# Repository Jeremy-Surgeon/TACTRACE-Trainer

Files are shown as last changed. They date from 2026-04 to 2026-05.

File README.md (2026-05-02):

# TACTRACE Trainer

### 24V DC Wire Fault Injection Training System

> **Status:** V1.4 Prototype Complete — Validation Ongoing
> **Author:** Jeremy Surgeon
> **Built by an active-duty F-15 avionics technician for hands-on troubleshooting training.**

---

## Overview

TACTRACE is a portable, bench-top hardware trainer that teaches electrical troubleshooting through controlled fault injection on a 24 V DC bus. Trainees diagnose realistic wiring faults, opens, shorts to ground, and shorts to power, using a digital multimeter and standard test leads, replicating the diagnostic process used on the flight line.

Most current electrical-troubleshooting instruction is either purely theoretical or relies on large, expensive classroom systems. TACTRACE replaces that with a small, rugged, low-cost trainer that travels to the unit, the schoolhouse, or the bench, and gives junior maintainers a safe, repeatable environment for voltage tracing, continuity checking, and structured fault isolation.

---

## Why This Matters

Junior maintainers learn electrical troubleshooting from manuals, lectures, and the occasional broken component handed to them on the flight line. That mix produces uneven readiness; some maintainers can isolate a wiring fault with a multimeter in two minutes, others swap parts until the symptom disappears. The difference is hands-on repetition, and current training programs offer very little of it.

TACTRACE closes that gap. It puts a controlled, repeatable, multimeter-driven fault scenario in the hands of every junior maintainer who needs one — at the unit, in the schoolhouse, or on a workbench. The result is faster fault isolation, fewer parts swapped on a hunch, and measurable improvement in troubleshooting proficiency before the maintainer is put into the troubleshooting loop on a real aircraft system.

---

## Skills Demonstrated

- **Electrical design** — 24 V DC fault-injection circuit, contact-arc mitigation, deliberate component selection (breaker vs. fuse, 1P4T rotary, snubber sizing)
- **Schematic capture (KiCad)** — V1.0 through V1.4 revisions, with controlled annotation
- **Mechanical design (FreeCAD)** — Pelican 1120 enclosure model, panel-engraving art, test-point ergonomics
- **Iterative engineering discipline** — five hardware revisions with documented rationale at each step
- **Technical writing** — schematic, BOM, training guide, instructor reference, design briefs
- **Training curriculum design** — trainee worksheet, instructor evaluation rubric, scenario-based fault diagnosis
- **Troubleshooting methodology** — voltage tracing, continuity testing, evidence-based fault isolation

---

## Current Version — V1.4: Rotary Selector Contact Protection Revision

V1.4 is the current hardware revision. The contact-protection components are installed and operational; quantitative validation under measured load is in progress.

### Hardware Configuration

- 24 V DC supply via panel-mount barrel jack (external 24 V 3 A 72 W AC/DC adapter)
- 5 A pull-type circuit breaker, aircraft-style (Klixon 2TC2-5)
- Panel-mount toggle power switch
- 4-position **1P4T rotary selector switch** (fault selector)
- LED load with 1 kΩ 1 W series resistor
- Female panel-mount banana jacks for TP1 / TP2 / TP3 / TP4
- Pelican 1120 enclosure with engraved control panel
- **V1.4 contact-protection additions:**
  - **100 nF ceramic capacitor** connected from TP3 node to ground — for switching transient suppression during selector transitions
  - **100 Ω resistor** on the **Position 4 (Short to Power)** path — for current limiting through the rotary contact

> Validation of the V1.4 contact-protection components under measured load is pending — _Needs peer review._ The detailed V1.4 schematic with the 100 Ω on the Pos 4 path is published at [`hardware/schematics/v1_4_schematic_detailed.pdf`](hardware/schematics/v1_4_schematic_detailed.pdf); post-release housekeeping (refdes, peer-review confirmation of the 100 Ω routing, component-rating confirmation) is tracked in [`archive/SCHEMATIC_V1_4_REGENERATION.md`](archive/SCHEMATIC_V1_4_REGENERATION.md).

### Fault Selector Positions

| Position | Fault Condition | Description |
| ---: | --- | --- |
| 1 | Normal | Healthy circuit — power flows through the load to ground |
| 2 | Open Circuit | Path between TP2 and TP3 broken |
| 3 | Short to Ground | TP3 shorted to ground return |
| 4 | Short to Power  | TP3 fed from supply through 100 Ω current-limit on this path |

A 100 nF capacitor is permanently connected from the TP3 node to ground; it is not switched by the selector and is active in all positions, providing transient suppression during selector transitions.

### Test Points

| Label | Location | Function |
| ----- | --- | --- |
| TP1 | After circuit breaker, before switch | Verifies protected input power |
| TP2 | After power switch, before selector  | Verifies power entering the fault selector |
| TP3 | After fault selector, before load | Displays the selected fault condition |
| TP4 | Load return / ground reference | System ground reference |

---

## System Architecture

```
+24 V Supply  ->  CB (5 A pull)  ->  TP1
                                       |
                                       v
                                Power Switch
                                       |
                                       v
                                      TP2
                                       |
                                       v
                       Fault Selector (1P4T rotary)
                       |-- Pos 1: Normal pass-through
                       |-- Pos 2: Open
                       |-- Pos 3: Short to Ground
                       '-- Pos 4: Short to Power (100 ohm on path)
                                       |
                                       v
                                      TP3 ---||--- GND   (100 nF transient cap)
                                       |
                                       v
                            1 kohm  ->  LED  ->  TP4 / GND
```

The rotary selector determines the behavior of the TP3 node, allowing the trainee to deduce the active fault by comparing measurements at TP1–TP4.

---

## V1.4 Schematic

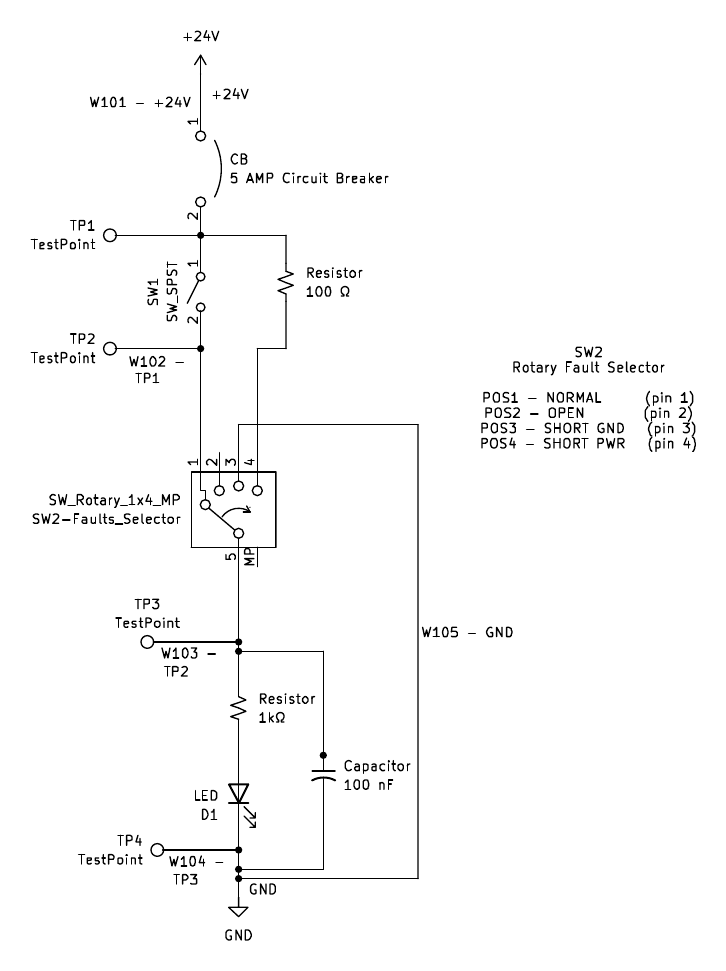
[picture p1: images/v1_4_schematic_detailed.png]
TACTRACE V1.4 Detailed Schematic


The V1.4 detailed schematic shows the full signal path from the +24 V supply through the circuit breaker (CB), main power switch (SW1), the 1P4T rotary fault selector (SW2), the 100 nF transient-suppression capacitor on the TP3 node, the 1 kΩ load resistor + LED, and back to GND. The 100 Ω current-limit feeding **Pos 4 (Short to Power)** is drawn explicitly, fed from the post-breaker rail. Reference designators (R1, C1, …) are not yet annotated and a peer-review confirmation of the 100 Ω routing intent is pending — see [`archive/SCHEMATIC_V1_4_REGENERATION.md`](archive/SCHEMATIC_V1_4_REGENERATION.md) for the post-release housekeeping list.

The PDF exports and KiCad source are in [`hardware/schematics/`](hardware/schematics/) and [`hardware/kicad/`](hardware/kicad/). A simplified block-level view is also available at [`hardware/schematics/v1_4_schematic_simplified.pdf`](hardware/schematics/v1_4_schematic_simplified.pdf) for orientation.

---

## V1.4 Panel Engraving

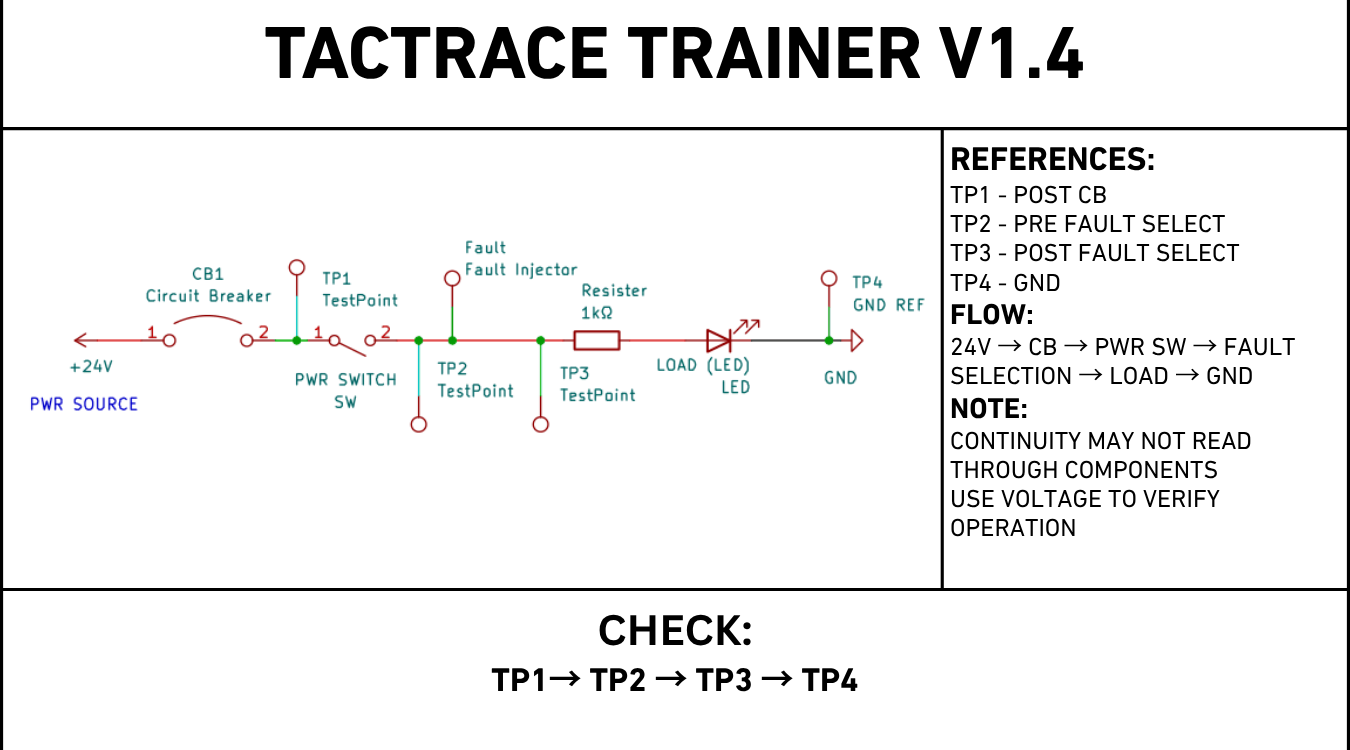
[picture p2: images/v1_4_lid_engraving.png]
TACTRACE V1.4 Lid Engraving Reference


The lid engraving doubles as a quick-reference card: test-point flow (TP1 → TP2 → TP3 → TP4), system flow (24 V → CB → PWR SW → FAULT SELECTION → LOAD → GND), and the reminder that continuity may not read through the load — voltage measurements should be used to confirm operation.

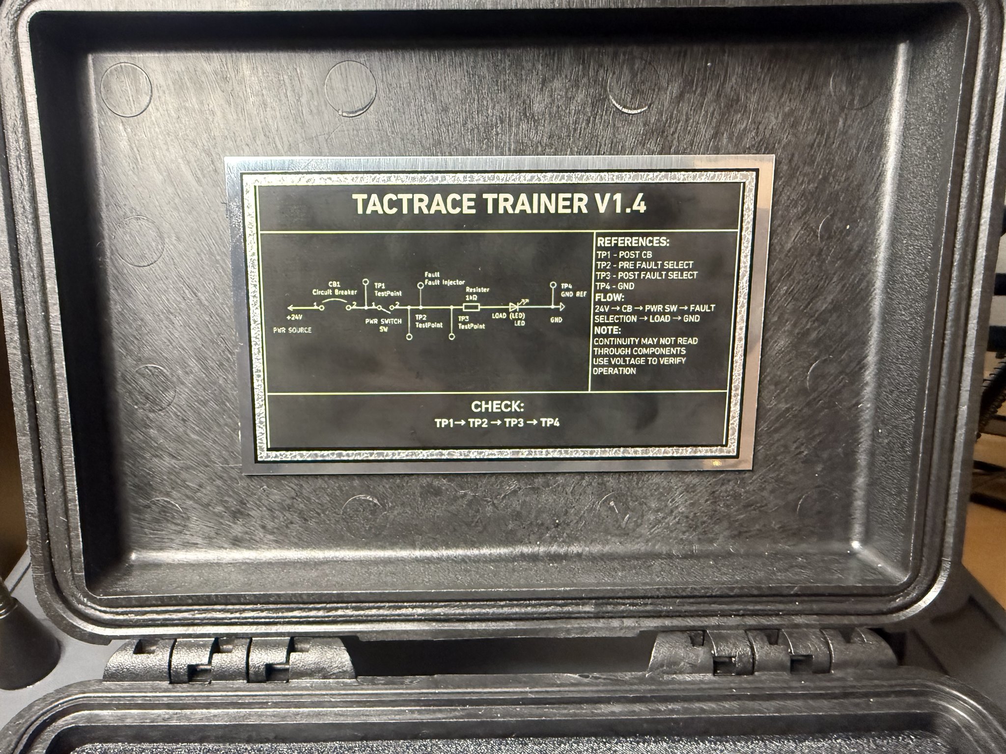
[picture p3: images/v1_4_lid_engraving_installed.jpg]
V1.4 Lid Engraving — Installed


The reference plate installed in the lid of the V1.4 enclosure — visible to the trainee while the unit is open and powered.

---

## Training Use Case

Instructors set the rotary to an unknown fault and ask the trainee to diagnose it. Trainees use TACTRACE to measure voltage at TP1–TP4 under each fault condition, recognize the electrical signature of opens, shorts to ground, and shorts to power, and practice systematic, evidence-based troubleshooting.

The full V1 training guide PDF (trainee worksheet + instructor reference + evaluation rubric) is in [`docs/TACTRACE_V1_Training_Guide.pdf`](docs/TACTRACE_V1_Training_Guide.pdf). The V1.4 quickstart — written for a maintainer who has never seen the device — is at [`docs/Quickstart.md`](docs/Quickstart.md). A V1.4-revised full training guide that maps the V1 three-test-point set to the V1.4 four-test-point set is in progress.

---

## Hardware & Documentation Deliverables

| Asset | Location | Status |
| --- | --- | --- |
| V1.4 detailed schematic (KiCad export, PDF) | [`hardware/schematics/v1_4_schematic_detailed.pdf`](hardware/schematics/v1_4_schematic_detailed.pdf) | Published |
| V1.4 simplified schematic (PDF) | [`hardware/schematics/v1_4_schematic_simplified.pdf`](hardware/schematics/v1_4_schematic_simplified.pdf) | Published |
| V1.4 KiCad source | [`hardware/kicad/`](hardware/kicad/) | Published |
| Bill of materials (CSV, machine-readable) | [`hardware/BOM.csv`](hardware/BOM.csv) | Published |
| Bill of materials (PDF, human-readable) | [`hardware/BOM.pdf`](hardware/BOM.pdf) | Published |
| V1.4 quickstart | [`docs/Quickstart.md`](docs/Quickstart.md) | Published |
| V1 training guide PDF (interim) | [`docs/TACTRACE_V1_Training_Guide.pdf`](docs/TACTRACE_V1_Training_Guide.pdf) | Interim — V1.4 revision in progress |
| User-feedback questionnaire (instrument) | [`docs/TACTRACE_User_Feedback_Questionnaire.csv`](docs/TACTRACE_User_Feedback_Questionnaire.csv) | Published |
| Peer-feedback summary (initial round, _n_ = 5) | [`docs/Peer_Feedback_Summary.md`](docs/Peer_Feedback_Summary.md) | Published |
| Demo video (~60 s) | Linked from the GitHub release page (file too large to commit to the repo body) | Release attachment |
| Enclosure CAD | [`hardware/enclosure/`](hardware/enclosure/) | **Deferred** — see Enclosure Status below |

---

## Validation & Initial Peer Feedback

Initial peer feedback was collected from **avionics maintainers** across three skill levels: two 3-Level Apprentices, two 5-Level Journeymen, and one 7-Level Craftsman (n = 5). All five reported the test points and controls were clear, and that the trainer helped them understand the troubleshooting concepts being taught. A summary of the responses and a transcript of the open-text themes is in [`docs/Peer_Feedback_Summary.md`](docs/Peer_Feedback_Summary.md); the underlying questionnaire is at [`docs/TACTRACE_User_Feedback_Questionnaire.csv`](docs/TACTRACE_User_Feedback_Questionnaire.csv) (surveyor identifying information masked).

This is **preliminary feedback at _n_ = 5** — it indicates that the trainer was usable and that the test-point layout communicated clearly to the reviewers. It does **not** constitute validation of training effectiveness, learning gains, retention, or transfer to flight-line tasks. A larger feedback round with pre/post measurement is a separate effort, not a V1.4 deliverable.

The V1.4 contact-protection components (100 nF capacitor, 100 Ω resistor) are installed and operational, but **quantitative validation under measured load is pending**. Where the schematic, BOM, or documentation states a value or placement that has not yet been confirmed by measured testing or independent peer review, that item is flagged in this README as **"Needs peer review"** or in the source files as **"Needs verification."**

---

## Enclosure Status

The TACTRACE V1.4 trainer is housed in a **Pelican 1120 enclosure** with an engraved control panel and engraved lid quick-reference plate (both V1.4 deliverables, photographed in this README). The mechanical layout is operational and trainee-validated by the initial peer-feedback round.

**A finalized 3-D enclosure CAD model is not part of the V1.4 release.** The CAD work is intentionally deferred while the project transitions from FreeCAD to **SolidWorks** (license pending). The current enclosure is documented through the panel-engraving art, the lid-engraving art, and the photographic record in [`images/`](images/) — not through a parametric CAD source. The `hardware/enclosure/` folder is reserved for the SolidWorks model and exported PDFs, and will be populated in a later revision.

This means the repo currently lets a maintainer **rebuild the V1.4 electrical system** from the schematic and BOM, but **does not** let them re-machine an identical enclosure from CAD without consulting the photographs and the panel-engraving art. The gap is intentional and documented; it is not an oversight.

---

## Key Engineering Decisions

- **5 A pull-type circuit breaker** instead of an automotive fuse — for realism, repeatability, and physical authority during instruction.
- **1P4T rotary selector switch** instead of a fan-style multi-pole — so each fault position electrically isolates the others.
- **Female panel-mount banana jacks** — for compatibility with standard maintainer test leads.
- **1 kΩ 1 W resistor** for thermal margin at 24 V (≈576 mW worst-case dissipation).
- **M2 mounting hardware** to reduce perfboard damage during enclosure work.
- **100 nF ceramic capacitor from TP3 to ground (V1.4)** — for switching transient suppression during selector transitions, suppressing the contact-arc transient that occurs as the rotary wiper makes/breaks under load. _Needs peer review under measured load._
- **100 Ω resistor on the Short-to-Power path (V1.4)** — for current limiting through the rotary contact during the Pos 4 transition. _Needs peer review under measured load._

---

## Known Limitations

- Mechanical rotary switching is the long-term scaling bottleneck — it limits fault count and introduces wear.
- Single-channel: only one fault can be active at a time.
- V1.4 arc-mitigation parts (100 nF / 100 Ω) reduce — but do not eliminate — switching transients on the rotary contacts. _Quantitative validation pending._
- TACTRACE is **not** certified for use on or with airworthy aircraft. Trainer use only.

---

## Version History

### V1.4 — Rotary Selector Contact Protection Revision

- Added 100 nF ceramic capacitor from TP3 to ground for switching transient suppression during selector transitions
- Added 100 Ω resistor on the Position 4 (Short to Power) path for current limiting through the rotary contact
- Refined V1.4 schematic and produced the lid-engraving panel quick-reference card

### V1.3 — Test Point Architecture Refinement

- Relocated TP1 to read protected input power (post-breaker, pre-switch)
- Separated protection, control, and fault-injection stages into distinct measurable nodes
- Improved diagnostic clarity for power distribution faults

### V1.2 — Aircraft-Realism Pass

- Replaced automotive fuse with aircraft-style 5 A pull-type circuit breaker
- Transitioned from male banana plugs to panel-mounted female banana jacks

### V1.1 — Enclosure Integration

- Integrated components into a Pelican 1120 enclosure with structured control panel layout
- Improved durability and portability for transport between training sites

### V1.0 — Functional Validation

- Initial circuit concept, four-position rotary fault selector, and bench-validated fault injection

The full per-version changelog is maintained in [`CHANGELOG.md`](CHANGELOG.md).

---

## Roadmap — Toward V2

V1.4 is the final mechanical-switching revision. V2 transitions to a solid-state, microcontroller-driven fault matrix.

- **MOSFET-based solid-state fault injection** replacing mechanical rotary switching
- **Microcontroller-controlled** scenario selection
- **16+ programmable faults**, including intermittent and time-based conditions
- Instructor-side scenario presets with **randomized fault delivery** for evaluation
- **Aircraft-style cannon plug connectors** to mirror real flight-line interfaces
- Improved enclosure layout, serviceability, and instrumentation
- Long-term: instructor-controlled training mode with student-evaluation logging, modular expansion across multiple wire systems, scalable deployable platform for squadrons, schoolhouses, and maintenance training units

A formal V2 design brief will be published in `docs/V2_design_brief.md`.

---

## Prototype Photos

The physical enclosure and front-panel layout are unchanged from V1.3; the V1.4 revisions are the engraved lid quick-reference and the internal contact-protection components on the rotary-selector paths.

### V1.4 Trainer — Lid Engraved, Front Panel Powered

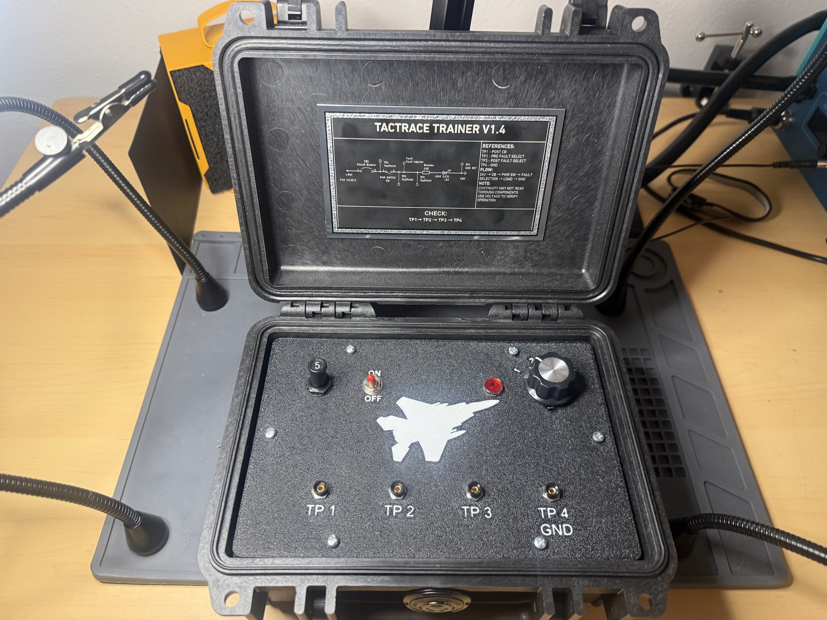
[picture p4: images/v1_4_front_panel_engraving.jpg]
TACTRACE V1.4 — engraved lid and powered front panel


### V1.4 Internal Wiring

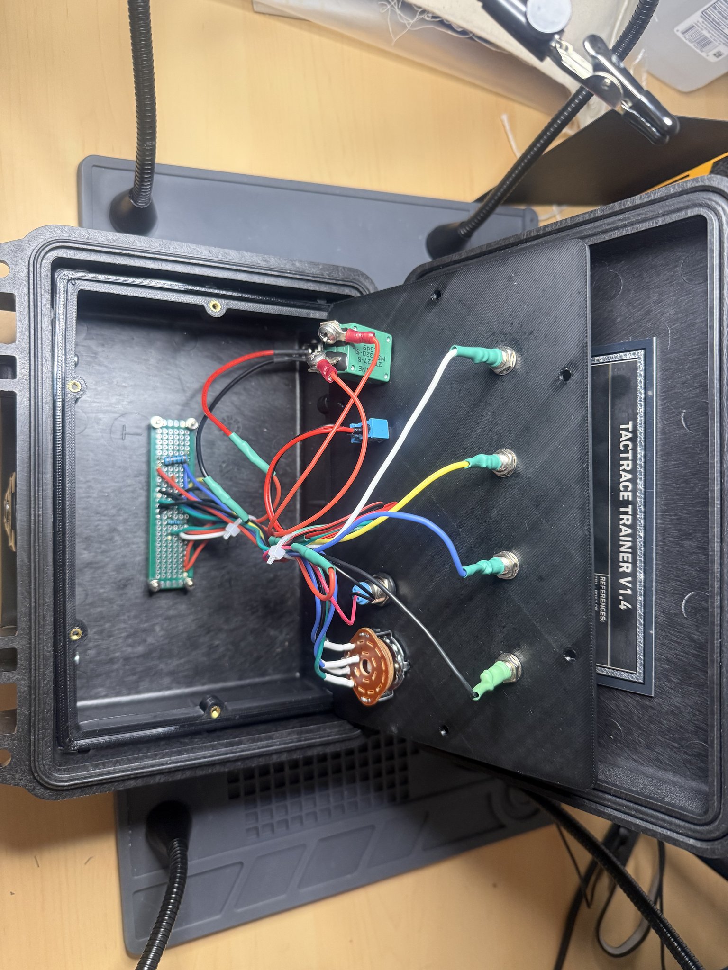
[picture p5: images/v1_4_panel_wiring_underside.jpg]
V1.4 Internal Wiring — Underside of Front Panel


### V1.4 Perfboard — Component Side

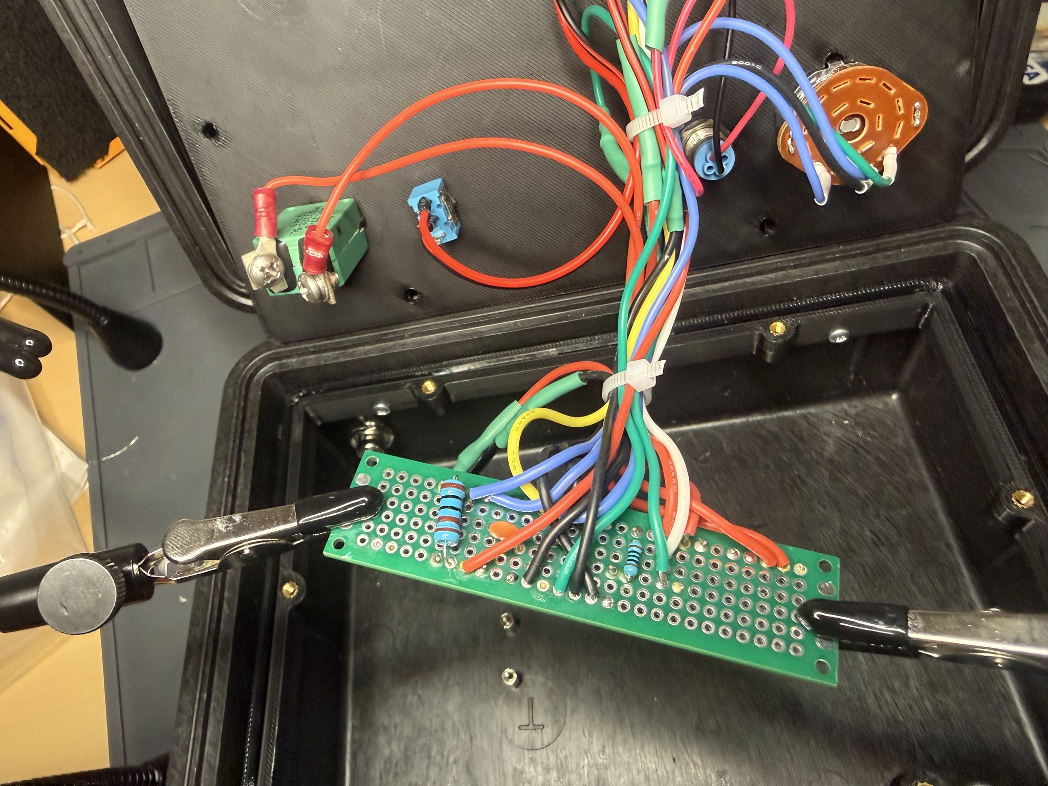
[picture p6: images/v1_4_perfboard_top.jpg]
V1.4 Perfboard — Top


### V1.4 Perfboard — Solder Side

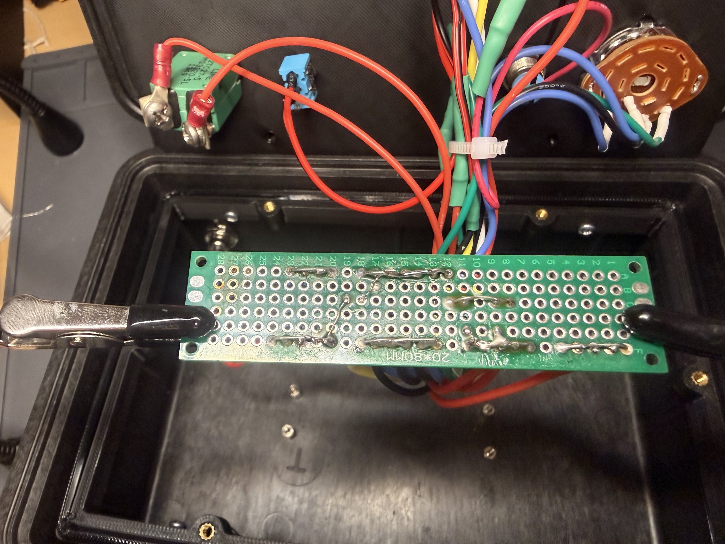
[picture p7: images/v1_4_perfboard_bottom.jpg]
V1.4 Perfboard — Bottom


### Earlier Revision Reference (V1.3)

The V1.3 prototype shots below are retained for revision-history context — the V1.4 trainer above is the current build.

<details>
<summary>V1.3 prototype photos</summary>

V1.3 Front Panel
V1.3 Front Panel — Powered
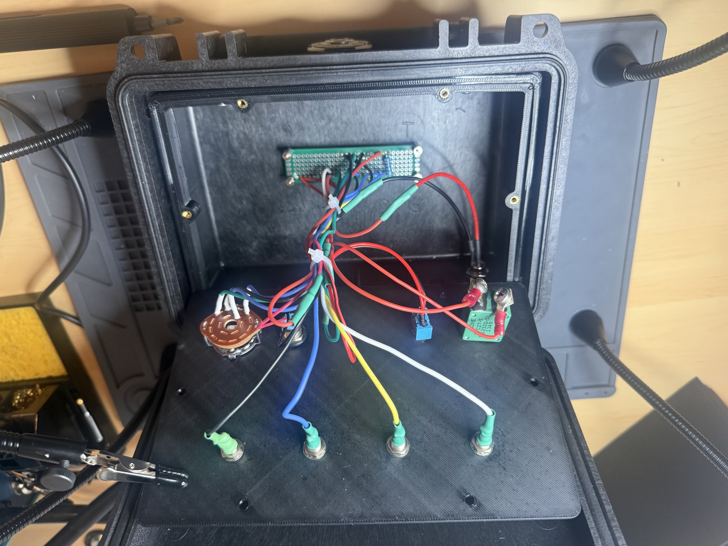
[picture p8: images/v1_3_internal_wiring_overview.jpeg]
V1.3 Internal Wiring

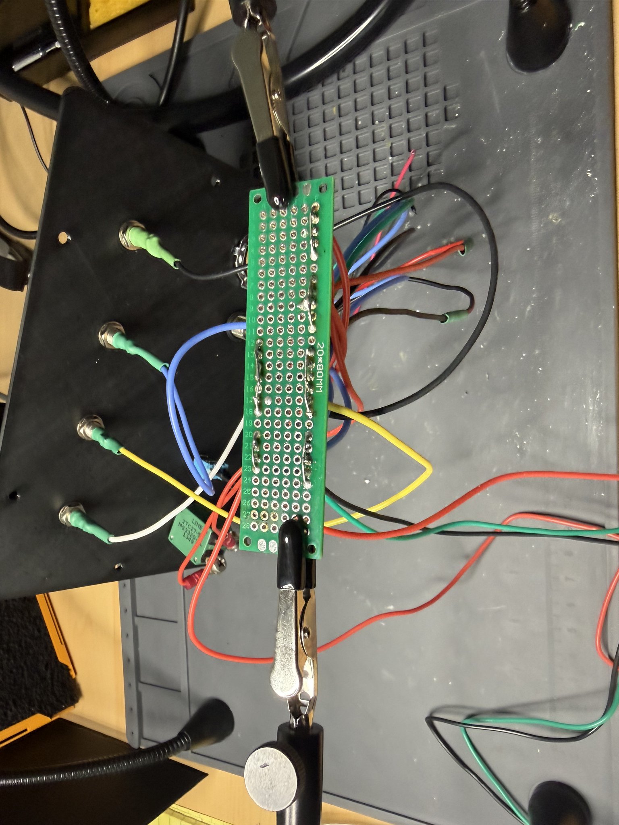
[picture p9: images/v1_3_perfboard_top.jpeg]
V1.3 Perfboard


</details>

---

## Lessons Learned

- Switching under load produces measurable contact arcing on a mechanical rotary — design has to plan for it, not ignore it.
- Switch and connector selection have an outsized effect on usability and safety; a 1P4T rotary selector behaves very differently from a fan-style multi-pole switch.
- Mechanical layout — test-point spacing, label placement, enclosure ergonomics — is as important to training value as the electrical design.
- Separating circuit protection, control, and fault injection into distinct measurable nodes (TP1 / TP2 / TP3) directly improves diagnostic clarity.
- Component selection (breaker vs. fuse, panel jacks vs. plugs, engraved labels) directly affects how the trainer feels in a maintainer's hands and how quickly trainees learn from it.

---

## Repository Layout

```
TACTRACE-Trainer/
├── README.md          ← project overview (this file)
├── CHANGELOG.md       ← per-version change history
├── LICENSE            ← project license
├── .gitignore         ← excluded build/backup/OS artifacts
├── docs/              ← training guides, design briefs, instructor reference
├── hardware/          ← KiCad schematic & PCB, BOM, FreeCAD enclosure, exports
├── images/            ← photos, schematic art, panel engraving art
├── logs/              ← bench validation, peer review notes, test records
└── versions/          ← per-version archive of source files (V1.0 → V1.4)
```

Each subfolder contains its own README.

---

## Disclaimer

TACTRACE is an independent training device. **It is not certified, qualified, or approved for use on or with airworthy aircraft.** It is intended solely for bench-top training of electrical fault-isolation skills. Engineering claims not yet validated by measured testing or peer review are marked **"Needs peer review."**

---

## Author

**Jeremy Surgeon** — TACTRACE Development

## Contributors

Design feedback, troubleshooting support, and prototype validation contributed by:

Nicholas Brewster · Joseph Chevalier · Derek Holt · Thomas Mattern · Lamonte McCoy · James Scott · Joshua Webb

---

## License

Released under the [MIT License](LICENSE). Hardware design files, training documentation, and panel art in this repository are distributed under the same terms.

> A hardware-specific license such as [CERN-OHL-P](https://ohwr.org/cern_ohl_p_v2.txt) (Permissive) may be adopted in a future revision for files under `hardware/`, while keeping documentation and software under MIT. This is under consideration; the project is currently MIT-only.

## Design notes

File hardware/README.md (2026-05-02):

# Hardware

Schematic, KiCad source, and bill-of-materials files for the TACTRACE Trainer.

## Contents

- **[`kicad/`](kicad/)** — KiCad project (`*.kicad_pro`, `*.kicad_sch`) for the V1.4 electrical design.
  - `TacTrace_V1.kicad_pro` — KiCad project file.
  - `TacTrace_V1_4_Full.kicad_sch` — V1.4 detailed schematic source (drawn at the component level).
  - `TacTrace_V1_4_Simple.kicad_sch` — V1.4 simplified topology source (block-level orientation view).
- **[`schematics/`](schematics/)** — PDF exports.
  - `v1_4_schematic_detailed.pdf` — V1.4 detailed schematic with the 100 nF cap, 100 Ω resistor, 1P4T rotary positions, and TP1-TP4 banana jacks individually labeled.
  - `v1_4_schematic_simplified.pdf` — V1.4 simplified block-level topology.
- **[`BOM.csv`](BOM.csv)** — Bill of materials, machine-readable. 15 installed line items + V2 candidate parts + Notes & Validation Items section.
- **[`BOM.pdf`](BOM.pdf)** — Bill of materials, human-readable (landscape, three-section layout matching the CSV).

## Planned (Future Revision)

- **`enclosure/`** — SolidWorks source (`*.SLDPRT`, `*.SLDASM`) and exported PDFs for the Pelican 1120 panel layout and lid engraving. **Deferred** while transitioning from FreeCAD to SolidWorks; license pending. The current enclosure is documented through panel-engraving art and the photographic record in [`../images/`](../images/).
- **`panel/`** — Panel-engraving art (lid engraving, label artwork), separated from photographs.
- **PCB layout (`*.kicad_pcb`)** — V1.4 is perfboard; a custom PCB is a V2 candidate.

## Conventions

- KiCad backups (`*-backups/`, `_autosave-*`) and FreeCAD backups (`*.FCBak`) are excluded via [`../.gitignore`](../.gitignore).
- Each export PDF is regenerated from the KiCad source whenever the source changes.
- Hardware revisions are tagged in [`../CHANGELOG.md`](../CHANGELOG.md).

## V1.4 Highlights

- **100 nF ceramic capacitor** from the TP3 node to ground — switching-transient suppression during selector transitions.
- **100 Ω resistor** on the Pos 4 (Short to Power) path — current limiting through the rotary contact. The schematic shows this resistor fed from the post-breaker rail; this is intentional, and the V1.4 quickstart documents the resulting diagnostic signature (TP3 still energizes in Pos 4 even with the main power switch off).
- **Updated lid engraving** with the TP1 → TP2 → TP3 → TP4 flow reference.

## Items Pending Verification

Tracked in [`../archive/SCHEMATIC_V1_4_REGENERATION.md`](../archive/SCHEMATIC_V1_4_REGENERATION.md):

- Reference designators (R1, R2, C1, …) for V1.4 components — currently labeled by value only.
- Independent peer-review confirmation that the 100 Ω placement (post-CB → rotary Pos 4, bypassing SW1) is the design-intended path. The schematic is consistent with the V1.4 teaching narrative; this is a confirmation step, not a known defect.
- 100 Ω wattage rating; 100 nF tolerance and voltage rating — both flagged in [`BOM.csv`](BOM.csv) Notes & Validation Items.

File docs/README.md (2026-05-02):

# Documentation

Training materials, instructor reference, and validation artifacts for the TACTRACE Trainer.

## Contents

- **[`Quickstart.md`](Quickstart.md)** — One-page V1.4 quickstart for a maintainer who has never seen the device. Includes setup procedure, fault-selector position table, test-point map, the recommended diagnostic procedure, and a list of "things that surprise first-time users" derived from initial peer feedback.
- **[`TACTRACE_V1_Training_Guide.pdf`](TACTRACE_V1_Training_Guide.pdf)** — V1 Training Guide: full 13-page document with trainee worksheet (Part I), instructor reference (Part II), expected-voltage and expected-resistance tables, and an instructor evaluation rubric. **Interim**: this PDF documents the V1 three-test-point set (TP1, TP2, TP3, GND); the V1.4 four-test-point set (TP1, TP2, TP3, TP4) is described in the V1.4 Quickstart and project README. A V1.4-revised full guide is in progress.
- **[`TACTRACE_User_Feedback_Questionnaire.csv`](TACTRACE_User_Feedback_Questionnaire.csv)** — Five anonymized responses from the initial peer-feedback round. Surveyor identifying information (names, ranks) is masked; reviewers are listed under R1-R5. Suitable for direct reuse as a Google Forms / Excel-import template if the original schema is restored.
- **[`Peer_Feedback_Summary.md`](Peer_Feedback_Summary.md)** — Initial peer-feedback round (n = 5) from avionics maintainers: two 3-Level Apprentices, two 5-Level Journeymen, one 7-Level Craftsman. Reports headline ratings, common improvement themes (selector-knob labeling, request for a written manual, V2 cannon-plug realism), and an explicit list of what this round does **not** establish.

## Planned (Next Revision)

- **`TACTRACE_V1.4_Training_Guide.pdf`** — V1.4-revised full training guide, mapping the V1 three-test-point set (TP1-TP3 + GND) to the V1.4 four-test-point set (TP1-TP4), and updating the expected-readings tables for the new TP layout.
- **`Trainee_Worksheet.pdf`** — Standalone trainee worksheet pulled out of the full guide for single-page printing.
- **`Instructor_Reference.pdf`** — Instructor-side reference (setup procedure, fault-mode tables, evaluation rubric) split out of the full guide for desk-reference use.
- **`V2_design_brief.md`** — Formal V2 design brief: requirements, architecture options, open questions, risk register.

## Conventions

- Published documents are PDF or Markdown. Source files (Pages, Word) are kept locally; only exported / Markdown documents are committed.
- Documentation revisions are tracked in [`../CHANGELOG.md`](../CHANGELOG.md) when they are released alongside a hardware revision.
- Claims that have not yet been validated by measured testing or independent peer review are marked **"Needs peer review"** in the README and the source files.
- Peer-feedback summaries report only what reviewers stated; broader claims about training effectiveness, learning gains, or transfer to flight-line tasks are explicitly **not** asserted unless backed by a designed study with adequate sample size.

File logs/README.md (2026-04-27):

# Logs

Bench-validation records, peer-review notes, and test logs for the TACTRACE Trainer.

## Planned Contents

- **`YYYY-MM_v1.4_bench_validation.md`** — Measured TP1–TP4 voltages and resistances at each fault position, with the rotary in each of positions 1–4, with the trainer powered (24 V) and unpowered.
- **`YYYY-MM_v1.4_arc_validation.md`** — Quantitative validation of the V1.4 contact-protection components (100 nF from TP3 to GND, 100 Ω on Pos 4 path) — switching-transient capture and analysis. *Pending.*
- **`YYYY-MM_peer_review_<reviewer>.md`** — Peer-review notes from contributors who have inspected or used the trainer.

## Conventions

- One file per validation event. Filename: `YYYY-MM_<topic>.md`.
- Each log records: hardware revision, supply voltage, instruments used, raw measurements, and an interpretation paragraph.
- Anything claimed in the README that has not yet been validated by a log entry is flagged in the README as **"Needs peer review."**

## Status

V1.4 has been bench-built and demonstrated; a formal validation log is pending and is the first deliverable for the V1.4 publication sprint Week 4.

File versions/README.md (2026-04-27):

# Versions

Per-version archives of the TACTRACE Trainer source files.

## Purpose

Each major hardware revision (V1.0, V1.1, V1.2, V1.3, V1.4, …) is archived in its own subfolder so that the exact state of the project at each revision is reproducible from this repository.

The `main` branch always reflects the latest revision; the per-version archives here exist for historical reference.

## Planned Contents

```
versions/
├── v1.0/   ← initial functional validation (Digital simulator .dig files, prototype notes)
├── v1.1/   ← Pelican 1120 enclosure integration
├── v1.2/   ← aircraft-style breaker, female banana jacks
├── v1.3/   ← TP1 relocation post-breaker (4-test-point architecture)
└── v1.4/   ← rotary selector contact protection (100 nF from TP3 to GND, 100 Ω on Pos 4 path)
```

Each version subfolder contains the schematic, BOM, panel art, and any documentation that was current at the time of that revision.

## Conventions

- A new subfolder is added when a hardware revision is tagged.
- Existing version folders are not edited after their tag is cut. Corrections and clarifications are made on `main`.
- Per-version changes are summarized in [`../CHANGELOG.md`](../CHANGELOG.md).

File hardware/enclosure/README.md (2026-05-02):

# enclosure/ — Deferred

This folder is reserved for the TACTRACE V1.4 enclosure CAD model and its exported PDFs. **It is intentionally empty in the V1.4 release.**

## Why deferred

The project is transitioning from FreeCAD to **SolidWorks** for parametric mechanical work. The SolidWorks license is pending. Rather than ship a half-converted FreeCAD source or a CAD model that would need to be reworked immediately after import, the V1.4 release documents the enclosure through:

- the engraved **front panel** (photographed in [`../../images/v1_4_front_panel_engraving.jpg`](../../images/v1_4_front_panel_engraving.jpg))
- the engraved **lid quick-reference plate** (art at [`../../images/v1_4_lid_engraving.png`](../../images/v1_4_lid_engraving.png), installed view at [`../../images/v1_4_lid_engraving_installed.jpg`](../../images/v1_4_lid_engraving_installed.jpg))
- the **internal wiring photograph** ([`../../images/v1_4_panel_wiring_underside.jpg`](../../images/v1_4_panel_wiring_underside.jpg))
- the **physical case**: a stock Pelican 1120 (BOM line item #1)

This is enough for a maintainer to **rebuild the V1.4 electrical system** from the schematic and BOM, but it is **not** enough to re-machine an identical enclosure from CAD. That is a known and accepted gap in the V1.4 release, not an oversight.

## What will go here

When the SolidWorks transition is complete, this folder will hold:

- **`*.SLDPRT`** — individual part models (Pelican 1120 panel, lid engraving, mounting brackets if any).
- **`*.SLDASM`** — top-level assembly.
- **`exports/`** — PDF panel-engraving art, dimensioned drawings, and STEP exports for downstream toolchains.

The enclosure update will land as its own commit, tracked in [`../../CHANGELOG.md`](../../CHANGELOG.md), and will not retroactively block the V1.4 release.

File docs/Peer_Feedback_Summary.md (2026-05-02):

# Peer Feedback Summary — V1.4 Initial Round

> **Status:** Initial peer feedback collected from avionics maintainers. **Preliminary, not validated proof of training value.** No conclusions about effectiveness should be drawn beyond what the responses themselves state.

## Reviewers (n = 5)

| Skill Level | Career Field | Count |
|---|---|---:|
| 3-Level (Apprentice) | Avionics | 2 |
| 5-Level (Journeyman) | Avionics | 2 |
| 7-Level (Craftsman) | Avionics | 1 |

Responses collected via the [`TACTRACE_User_Feedback_Questionnaire.csv`](TACTRACE_User_Feedback_Questionnaire.csv) survey instrument. Surveyor identifying information has been masked; responses are listed under anonymized IDs (R1-R5).

## Summary of responses

- **Ease of use:** 1, 1, 1, 2, 3 on a 1-5 scale (1 = easiest). Four of five rated 1 or 2.
- **Clarity of test points and controls:** all five rated 1 (clearest).
- **"Did the trainer help you understand troubleshooting concepts?":** all five answered "Yes, significantly."
- **Concepts the trainer reinforced (reviewer-selected):** voltage measurement, continuity testing, fault isolation, understanding open and short circuits, and (verbatim from one reviewer) the way the test leads themselves can complete the circuit.

These responses indicate the trainer was **easy enough to use and clear enough in its test-point presentation** for the five reviewers, who all reported some training-value signal. Drawing broader conclusions (effectiveness across cohorts, transfer to flight-line tasks, retention) is **not** supported by this sample size and is **not claimed**.

## Common improvement themes

Three themes appeared in the open-text responses, each surfaced by more than one reviewer:

1. **The fault selector knob does not communicate which fault is active.** Surfaced by R1, R2, R3, and R4. R3 specifically asked for "a key or manual that dictates what fault is being induced into circuit." Addressed in V1.4 by the **engraved lid quick-reference plate** and the new [`Quickstart.md`](Quickstart.md), which tabulates the four positions explicitly.
2. **A user manual / written quick-reference is wanted.** R2 asked for "a users manual for the tester... [with] applicable questions"; R5 suggested "a paper that has questions and answers on it, that new guys could answer." Addressed by the V1 Training Guide PDF in this folder (and by the V1.4 revision currently in progress).
3. **Aircraft-style cannon connectors for realism.** Surfaced by R1 and R2. **Already on the V2 roadmap** — see the README "Roadmap — Toward V2" section. Not a V1.4 deliverable.

## Notes from individual reviewers (verbatim themes)

- "Voltage may still vary when circuit breaker is pulled (~0.000-0.099 V) — still means no voltage." → captured in [`Quickstart.md`](Quickstart.md) under "Things that surprise first-time users."
- "Don't touch leads with fingers as it will affect reading." → captured in `Quickstart.md`.
- "Leads can complete circuit and turn on light." → captured in `Quickstart.md`.
- "Maybe a pre-TP for the circuit breaker to see if voltage is coming in" (R1); "Maybe add some test points to allow technicians the ability to shoot for a popped circuit breaker" (R3) → noted as a potential V1.5 / V2 consideration; not a V1.4 change.
- "Multiple lights at the beginning of the circuit and the end" (R4) → V2 candidate (multi-load visualization); not a V1.4 change.

## What this round does **not** establish

- It does not establish training effectiveness across a representative cohort. *n* = 5.
- It does not establish learning gains, time-to-fault-isolation improvement, or knowledge retention.
- It does not constitute validation of the V1.4 contact-protection components (100 nF cap, 100 Ω resistor) under measured electrical load. That validation remains **"Needs peer review"** in the README.

A larger feedback round, ideally with pre/post measurement of fault-isolation time on a controlled set of faults, would be the next step toward demonstrating training value. That work is **not** part of the V1.4 release.

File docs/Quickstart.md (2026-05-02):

# TACTRACE Trainer — V1.4 Quickstart

A one-page reference for a maintainer who has never seen the device. For the full training procedure (trainee worksheet + instructor reference + evaluation rubric), see the V1 Training Guide PDF in this folder until the V1.4-revised guide is published.

> **Document status:** V1.4 quickstart, draft. The full V1.4 Training Guide is in revision (V1 source PDF retained as `TACTRACE_V1_Training_Guide.pdf`). Mapping the V1 test-point set (TP1-TP3 + GND) to the V1.4 four-test-point set (TP1-TP4) is the core change between the two revisions.

---

## Equipment

- TACTRACE Trainer (V1.4)
- 24 V DC 3 A power adapter (5.5 x 2.1 mm barrel) — included
- Digital multimeter with standard test leads

## What you have

A 24 V DC bench-top trainer with a 1P4T rotary fault selector and four panel-mount banana-jack test points. The lid carries an engraved quick-reference card showing the test-point order, the system flow, and the troubleshooting reminder that **continuity may not read through the load — use voltage to verify operation.**

## Setup procedure

1. Plug the 24 V adapter into the trainer's panel-mount barrel jack.
2. Confirm the **circuit breaker (CB)** is **pushed in** (closed).
3. Set the **rotary fault selector** to the position the instructor has assigned (1, 2, 3, or 4).
4. Turn the **power switch ON** to begin the diagnostic exercise.

## Fault selector positions

| Position | Fault Condition | What it does |
|---:|---|---|
| 1 | Normal | Healthy circuit — power flows to the load through the rotary |
| 2 | Open Circuit | Path between the selector and the load is broken |
| 3 | Short to Ground  | The post-selector node (TP3) is shorted to ground return |
| 4 | Short to Power | TP3 is fed from the supply through a 100 Ω current-limit on this path |

> **V1.4 teaching note (Pos 4):** the 100 Ω current-limit feeds Pos 4 from the post-breaker rail, so TP3 still energizes in Pos 4 even with the **main power switch OFF**. That is the diagnostic signature that distinguishes Short-to-Power from the other faults.

## Test points

| Label | Location | Function |
|---|---|---|
| TP1 | After circuit breaker, before power switch | Verifies protected input power |
| TP2 | After power switch, before fault selector | Verifies power entering the fault selector |
| TP3 | After fault selector, before load | Displays the selected fault condition |
| TP4 | Load return / ground reference | System ground reference |

## Diagnostic procedure

Voltage measurements are taken **with the black probe on TP4 (GND)** and the red probe stepped through TP1, TP2, and TP3. Don't assume voltage propagates linearly down the chain — read each test point independently and **compare the readings** to identify which node behaves anomalously for the active fault.

1. **Reference probe at TP4 (GND).** Set the multimeter to DC volts. Keep the black probe on TP4 for every voltage reading in this procedure.
2. **Capture the four readings.** With power **ON**, read TP1, TP2, and TP3 in any order. Record each voltage. Note the LED state (on / off / dim).
3. **Compare, don't assume.** Identify the test point where the reading diverges from the expected value and the test point where it agrees. The pair tells you where the fault is — not the order.
4. **Distinguish Pos 4 from the rest.** **TP3 may remain energized in Position 4 even with the main power switch OFF**, because the 100 Ω current-limit feeds Pos 4 from the post-breaker rail. If TP3 still reads near +24 V with the switch off, the rotary is on Pos 4 (Short to Power).
5. **Power OFF for any continuity / resistance check.** Pull the breaker for resistance work. **Do not perform resistance tests with the supply energized.**
6. **Record and document.** Note the fault you identified and your reasoning (which TP-pair was the deciding evidence). The full per-fault expected-reading table is in the V1 Training Guide PDF (Part II — Instructor Reference).

## Things that surprise first-time users (from peer feedback)

- The selector knob does not name the faults at the panel — refer to the lid-engraved reference card or this Quickstart.
- A pulled circuit breaker can read **0 V** at TP1, or read very low (≤ 0.1 V) due to multimeter noise — both indicate "no protected input power."
- Touching probe tips with bare fingers can shift readings; keep fingers off the metal.
- The probe leads themselves can complete the circuit and light the LED if you bridge the load — a useful demonstration, but be aware of it during measurement.
- Continuity (audible) may not beep through the LED + 1 kΩ load even when the path is intact — use **voltage** to verify operation.

## Safety

- **No certification.** TACTRACE is a bench-top trainer only. It is **not** certified for use on or with airworthy aircraft.
- Resistance / continuity checks: **power OFF**, breaker pulled.
- Do not short test points together with bare probe leads while power is applied beyond what the exercise requires.
- The 5 A breaker provides primary input protection; the 100 Ω in the Pos 4 path provides current limiting through the rotary contact during Short-to-Power. Both are wear-rated, not safety-rated for high-energy faults.

---

> Where this quickstart and the V1 PDF disagree, the V1.4 hardware (this quickstart) is authoritative. Items still requiring peer review are flagged in the [project README](../README.md) and the [CHANGELOG](../CHANGELOG.md).

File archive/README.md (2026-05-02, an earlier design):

# archive/

This folder holds **internal traceability artifacts** for the TACTRACE Trainer project — superseded drafts, regeneration TODOs, and historical exports that should not be deleted but also do not belong in `images/`, `hardware/`, or `docs/`.

It is published with the repo so that reviewers can see the full V1.4 paper trail, including known gaps, without those gaps polluting the user-facing folders.

## Current contents

- [`SCHEMATIC_V1_4_REGENERATION.md`](SCHEMATIC_V1_4_REGENERATION.md) — schematic open-item tracker. The detailed V1.4 schematic is now published at [`../hardware/schematics/v1_4_schematic_detailed.pdf`](../hardware/schematics/v1_4_schematic_detailed.pdf) and embedded in the project README. The remaining items are a "Resister" → "Resistor" typo correction, reference-designator additions (R1, C1, …), and peer-review confirmation of the 100 Ω routing intent.

## What does not belong here

- Photos, schematics, or panel art that are the current canonical V1.4 deliverables — those go in `images/`.
- KiCad / FreeCAD / BOM source files — those go in `hardware/`.
- Training documents, instructor materials — those go in `docs/`.
- Bench validation logs, peer review notes — those go in `logs/`.
- Per-version source archives — those go in `versions/`.

If a file in `archive/` has been superseded **and** is no longer needed for traceability (e.g., a draft replaced by a peer-reviewed final), record the supersession in this README and remove the file in a documented commit.

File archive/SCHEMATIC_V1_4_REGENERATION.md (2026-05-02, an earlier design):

# V1.4 Schematic — Outstanding Items

**Status:** Mostly resolved as of 2026-04-29.
**Owner:** Jeremy Surgeon

## Resolved in the V1.4 release

- **Detailed V1.4 schematic published** at [`../hardware/schematics/v1_4_schematic_detailed.pdf`](../hardware/schematics/v1_4_schematic_detailed.pdf), with KiCad source at [`../hardware/kicad/`](../hardware/kicad/) and a PNG render at [`../images/v1_4_schematic_detailed.png`](../images/v1_4_schematic_detailed.png) (embedded in the project README).
- **Typo corrected** in the schematic source: "Resister" → "Resistor" on both the 1 kΩ load resistor and the 100 Ω current-limit resistor.
- **All V1.4 components drawn explicitly:** CB (5 A), TP1, SW1 (SW_SPST), TP2, the 100 Ω resistor on the Pos 4 path, the 1P4T rotary fault selector with all four positions labeled (POS1 NORMAL, POS2 OPEN, POS3 SHORT GND, POS4 SHORT PWR), TP3, the 1 kΩ load resistor, the LED (D1), the 100 nF capacitor across the load, and TP4 / GND.

## Items still open (post-V1.4 housekeeping)

These do **not** block the V1.4 release:

- [ ] **Reference designators.** V1.4 components are labeled by value only. Standard refdes (R1, R2, C1, …) should be added in the next schematic revision.
- [ ] **Peer-review confirmation of the 100 Ω routing.** The schematic shows the 100 Ω feeding rotary Pos 4 from the **post-CB rail** (bypassing SW1). This is consistent with the V1.4 teaching narrative documented in [`../docs/Quickstart.md`](../docs/Quickstart.md): TP3 still energizes in Pos 4 with the main switch off — that is the diagnostic signature. Open item is an independent peer-review confirmation that this is the design-intended path.
- [ ] **Component ratings.** The 100 Ω wattage rating and the 100 nF tolerance + voltage rating are tracked in [`../hardware/BOM.csv`](../hardware/BOM.csv) under "Notes & Validation Items" and should be confirmed against the installed parts.

Until each box checks, the V1.4 contact-protection components remain **"Needs peer review"** in the README under quantitative validation.

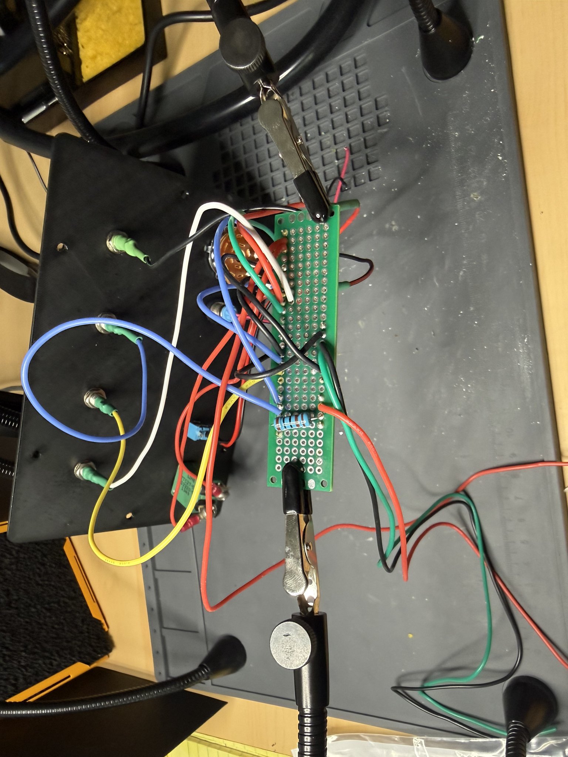
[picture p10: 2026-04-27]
images/v1_3_perfboard_bottom.jpeg

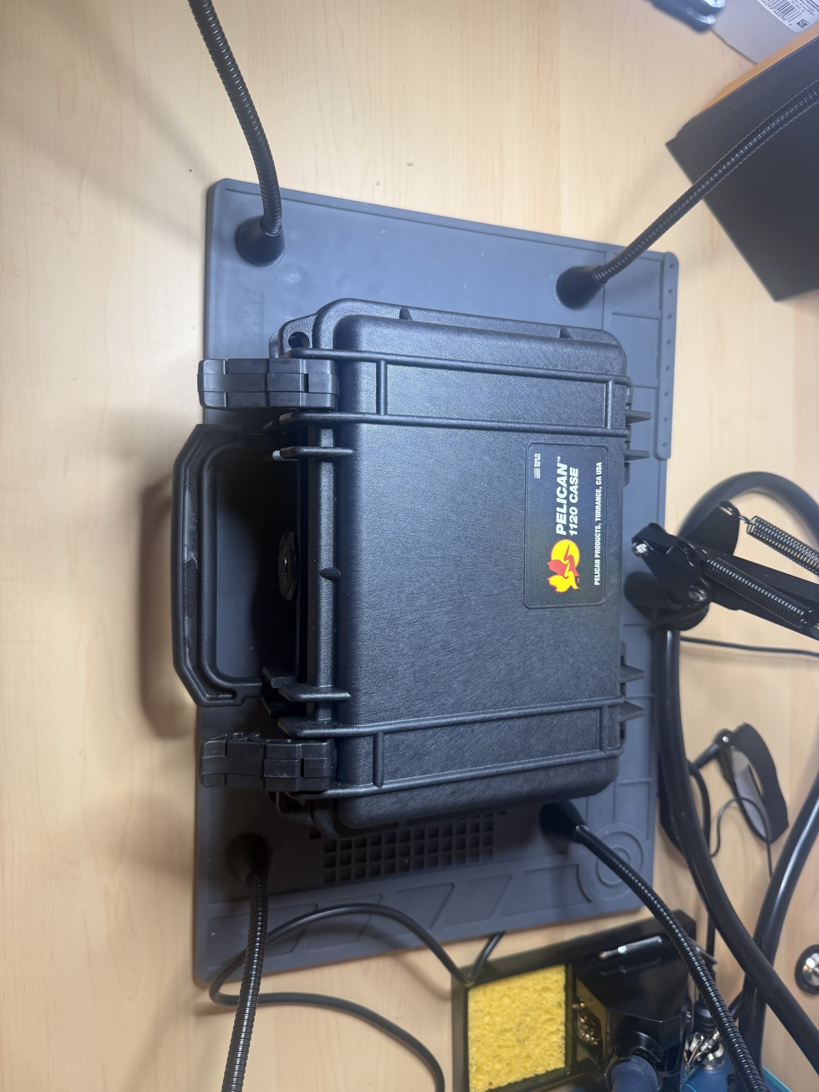
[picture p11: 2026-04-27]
images/v1_3_enclosure_closed.jpeg

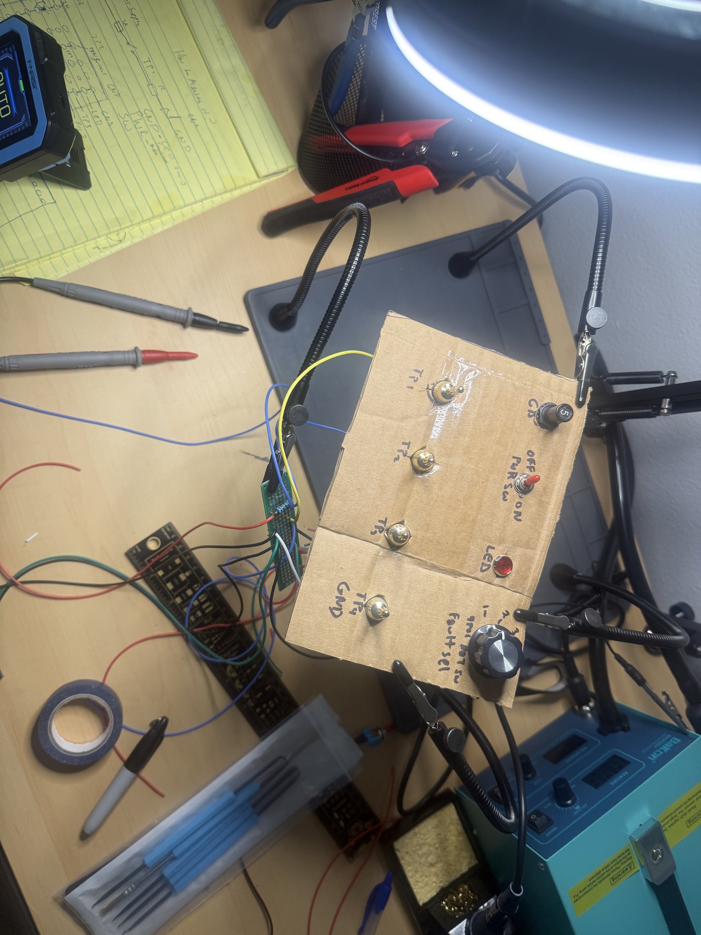
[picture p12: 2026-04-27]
images/v1_0_prototype_cardboard_layout.jpeg

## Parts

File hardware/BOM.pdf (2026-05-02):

# TACTRACE Trainer Bill of Materials

### As of Apr 26 2026 | Current build: V1.4 Prototype Complete — Validation Ongoing

It e m | Qty Used | Category | Component | Specification | Manufacturer / Model | Source | Pack age Qty | Packag e Cost | Unit Cost | Extend ed Cost | Status | Version Added | Notes
1 | 1 | Enclosure | Pelican 1120 Case | Portable hard protective case | Pelican 1120 | Supply Proc urement | 1 | 30.32 | 30.3 2 | 30.32 | Installed | V1.1 | Primary enclosure
2 | 1 | Electrical | Rotary Selector Switch | 1P4T rotary selector switch | Not specified | Amazon | 2 | 12.48 | 6.24 | 6.24 | Installed | V1.0 | Fault selector; 2-pack purchase
3 | 1 | Electrical | Circuit Breaker | 5A pull-type breaker | Klixon 2TC2-5 | Supply Proc urement | 1 | 33.37 | 33.3 7 | 33.37 | Installed | V1.2 | Aircraft-style circuit protection
4 | 1 | Electrical | Power Switch | 2-position toggle switch; 5A 125VAC / 3A 250VAC | MST-1 | Donated | 1 | 0 | 0 | 0 | Installed | V1.0 | Main power control
5 | 1 | Electrical | Power Supply | 24V 3A 72W AC/DC adapter; 5.5x2.1mm output | Not specified | Amazon | 1 | 16.99 | 16.9 9 | 16.99 | Installed | V1.0 | External power source
6 | 4 | Electrical | Banana Jacks | 4mm panel-mount banana jacks | Not specified | Donated | 4 | 0 | 0 | 0 | Installed | V1.2 | TP1 TP2 TP3 TP4
7 | 1 | Electrical | LED Indicator | 10mm 12-24V AC/DC metal panel LED | Not specified | Amazon | 12 | 7.99 | 0.66 58 | 0.6658 | Installed | V1.0 | Load indicator; 12-pack purchase
8 | 1 | Electrical | Load Resistor | 1k ohm 1W ±1% metal film resistor | Not specified | Amazon | 100 | 7.41 | 0.07 41 | 0.0741 | Installed | V1.0 | LED/load path; bulk pack
9 | 1 | Electrical | Current-Limit Resistor | 100 ohm resistor | Not specified | Kit | 1 | 0 | 0 | 0 | Installed | V1.4 | Position 4 path; wattage rating TBD
1 0 | 1 | Electrical | Capacitor | 100nF ceramic capacitor | Not specified | Kit | 1 | 0 | 0 | 0 | Installed | V1.4 | Connected from TP3 node to ground for transient suppression; tolerance TBD
1 1 | 1 | Electrical | Perfboard | Double-sided prototype PCB board; 2 cm x 8 cm | Not specified | Amazon | 32 | 7.99 | 0.24 97 | 0.2497 | Installed | V1.0 | Main circuit board; bulk pack
1 2 | 1 | Electrical | DC Barrel Jack | Female threaded panel adapter; 5.5mm x 2.1mm; 18AWG leads | Not specified | Amazon | 8 | 10.99 | 1.37 38 | 1.3738 | Installed | V1.0 | Power input with dustproof plug
1 3 | 1 | Mechanic al | Hookup Wire | Assorted internal wiring | Not specified | Existing Stock | 1 | 0 | 0 | 0 | Installed | V1.0 | Internal harness wiring
1 4 | 1 | Mechanic al | Mounting Hardware | M2 screws nuts and spacers | Not specified | Existing Stock | 1 | 0 | 0 | 0 | Installed | V1.0 | Perfboard and component mounting
1 5 | 1 | Labeling | Panel Engraving | Lid quick-reference graphic | In-house design | In-House | 1 | 0 | 0 | 0 | Installed | V1.4 | Training reference plate and system flow guide

## V2 Candidate Parts (planning only — not part of V1.4 build)

Ite m | Category | Candidate Component | Purpose | Likely Version | Status | Cost Basis | Notes
1 | Future Upgrade | MOSFET-based solid-state fault matrix | Replace mechanical selector with controlled switching | V2 | Planned | TBD | Evaluate current rating, gate drive, fault isolation, thermal margin
2 | Future Upgrade | Microcontroller control board | Scenario logic, randomization, instructor mode | V2 | Planned | TBD | Could support timed/intermittent faults and student evaluation modes
3 | Future Upgrade | Aircraft-style cannon connectors | More realistic maintainer interface | V2 | Planned | TBD | Connector selection should balance realism, cost, durability, and wiring complexity
4 | Future Upgrade | Improved enclosure/panel layout | Serviceability and instructor usability | V2 | Planned | TBD | SolidWorks transition planned before end of Week 2

## Notes & Validation Items

Topic | Current Assumption | Validation Needed | Repo Location
Capacitor | 100nF ceramic from TP3 node to ground | Confirm tolerance and voltage rating | hardware/BOM.csv
100 ohm resistor | On Position 4 short-to-power path | Confirm wattage rating and precise placement in detailed schematic | hardware/BOM.csv
Costs | Pack costs prorated into unit cost where package quantity is known | Confirm vendor receipts for exact prices | hardware/BOM.csv
Donated/stock parts | Cost entered as $0 for build-cost tracking | Optional replacement value can be added later | hardware/BOM.csv
Cost Method | Estimated Cost Used in Build prorates package purchases by quantity used; Total Package Spend reflects full package cost in BOM rows. | Review receipts before publication if exact financial accuracy matters. | BOM summary

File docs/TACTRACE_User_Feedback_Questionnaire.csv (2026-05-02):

Reviewer ID | Timestamp | AFSC / Career Field | Skill Level | Have you used similar training aids before? | How easy was the trainer to use? | How clear were the test points and controls (TP1–TP4, switches, etc.)? | Did the trainer help you understand troubleshooting concepts? | Which concepts did this trainer help reinforce? (Select all that apply) | At what experience level do you think this trainer is most useful? | What did you like most about the trainer? | What was confusing or difficult to understand? | If you could change or improve one thing, what would it be? | What additional features or capabilities would you want to see? | Any other thoughts, ideas, or feedback?
R1 | 2026/04/28 | Avionics | 5-Level (Journeyman) | Yes | 3 | 1 | Yes, significantly | Voltage measurement;Continuity testing;Fault isolation;How the leads themself can complete the circuit and turn on the light | 5-Level | Easy to transport, clear diagram, simple | selector settings | More notes and tips | Canon plug for realism | Voltage may still very when circuit breaker is pull (.000-.099) just something that happens.. still means no voltage (for note section) Don't touch leads with fingers as it will affect reading (for notes section) Leads can complete circuit and turn on light (for note section) A sheet to say what each selector (1-4) does. Could help with how to use system and understand how it behaves in different scenarios. Setting 1 (Normal Operationals) • Maybe a pre-TP for the circuit breaker to see if voltage is coming in and not a faulty circuit breaker or charger Canon plug version for realism
R2 | 2026/04/28 | Avionics | 5-Level (Journeyman) | Yes | 1 | 1 | Yes, significantly | Continuity testing;Fault isolation;Understanding open circuits;Understanding short circuits | 3-Level | I liked how the tester has a variety of faults that allow for troubleshooting. | labeling the fault knob will help identify what its purpose is for first time users and label the cb. | i’d include a users manual for the tester and have the user manual include applicable questions. | I’d like to see cannon plugs being included | nope
R3 | 2026/04/28 | Avionics | 7-Level (Craftsman) | No | 1 | 1 | Yes, significantly | Continuity testing;Fault isolation;Understanding short circuits | 3-Level | The light on the trainer provides an example of what shorted wiring would look like on a switch/light | The fault selection knob does not define what fault is being induced into the circuit and may confuse some newer technicians. | Add a key or manual that dictates what fault is being induced into circuit. | Maybe add some test points to allow technicians the ability to shoot for a pop circuit breaker since we don’t really work with them that often but can provide them with useful information/knowledge | None
R4 | 2026/04/30 | Avionics | 3-Level (Apprentice) | Yes | 2 | 1 | Yes, significantly | The settings on the meter | 3-Level | It seemed like a puzzle at first, I really like it! | The fault injector switch | Nothing | Maybe multiple lights that are supposed to come on, in the beginning of the circuit and the end of the circuit | It’s was a pretty good device for teaching
R5 | 2026/04/30 | Avionics | 3-Level (Apprentice) | No | 1 | 1 | Yes, significantly | Voltage measurement;Continuity testing;Fault isolation;Understanding open circuits;Understanding short circuits | 3-Level | It’s an easy circuit to understand and practice | No. It’s a good small example that will help on a larger scale. | N/a | N/a | Maybe a paper that has questions and answers on it, that new guys could answer. Just to make sure they are actually learning and not just playing with it

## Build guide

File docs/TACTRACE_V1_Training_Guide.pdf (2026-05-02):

Document ID: TACTRACE-V1-TRN Revision: A

# TACTRACE V1

## Wire Fault Troubleshooting Trainer

System: Tactical Circuit Tracing & Evaluation System Version: V1 Prototype
Supply Voltage: 24V DC

Document Control

Revision History

Training Objective
This trainer teaches maintainers to diagnose electrical wiring faults using voltage and resistance measurements.

Skills trained:
- Voltage measurement
- Continuity testing
- Fault isolation
- System troubleshooting logic

## Safety

- Ensure power supply is OFF before resistance tests.
- Verify supply voltage is 24V DC before connecting trainer.
- Do not short test points with probes.
Field | Value
Documen t | TACTRACE V1 Training Guide
Revision | A
Date | 2026-03-12
Author | Jeremy Surgeon
System | 24V DC Fault Injection Trainer
Revision | Date | Change
A | 2026-03-12 | Initial prototype documentation

# PART I — TRAINEE WORKSHEET

## Objective

Diagnose an unknown wiring fault using:

- Voltage measurements
- Resistance / continuity testing

The instructor will set the trainer to an unknown fault condition.

Your task is to determine the fault.

# Equipment Required

- Digital Multimeter
- TACTRACE Trainer
- 24V Power Supply

# Test Points

# Phase 1 — Voltage Test (Power ON)

Procedure

Test Point | Description
TP1 | Source voltage after power switch
TP2 | Wire after fault selector
TP3 | Load return
GND | Ground reference

1. Turn the power switch ON.
2. Set the multimeter to DC Voltage.
3. Measure voltage relative to GND.

Record Measurements

LED State

☐ ON

☐ OFF

# Phase 2 — Resistance / Continuity Test (Power OFF)

! Important: Turn the power switch OFF before performing resistance tests.

Set the multimeter to:

Ω (resistance) or continuity mode

Test 1 — TP1 to TP2

Measure resistance between:

TP1 → TP2

Test Point | Measured Voltage
TP1 | ______ V
TP2 | ______ V
TP3 | ______ V
Measurement | Result
Resistance | ______ Ω

Test 2 — TP2 to TP3

Measure resistance between:

TP2 → TP3

Test 3 — TP2 to Ground

Measure resistance between:

TP2 → GND

# Fault Diagnosis

Using both voltage and resistance measurements, determine the fault.

☐ Normal Operation
☐ Open Circuit
☐ Short to Ground
☐ Short to Power

Troubleshooting Logic HINTs
If TP1 = 24V → Power source is good
If TP2 = 0V but TP1 = 24V → Fault between TP1 and TP2 If TP2 = 24V with power switch OFF → Short to Power
Continuity | ☐ Yes ☐ No
Measurement | Result
Resistance | ______ Ω
Continuity | ☐ Yes ☐ No
Measurement | Result
Resistance | ______ Ω
Continuity | ☐ Yes ☐ No

If TP2 = 0V and continuity to GND → Short to Ground

# Troubleshooting Explanation

Explain how you determined the fault.

__________________________________________________

__________________________________________________

__________________________________________________

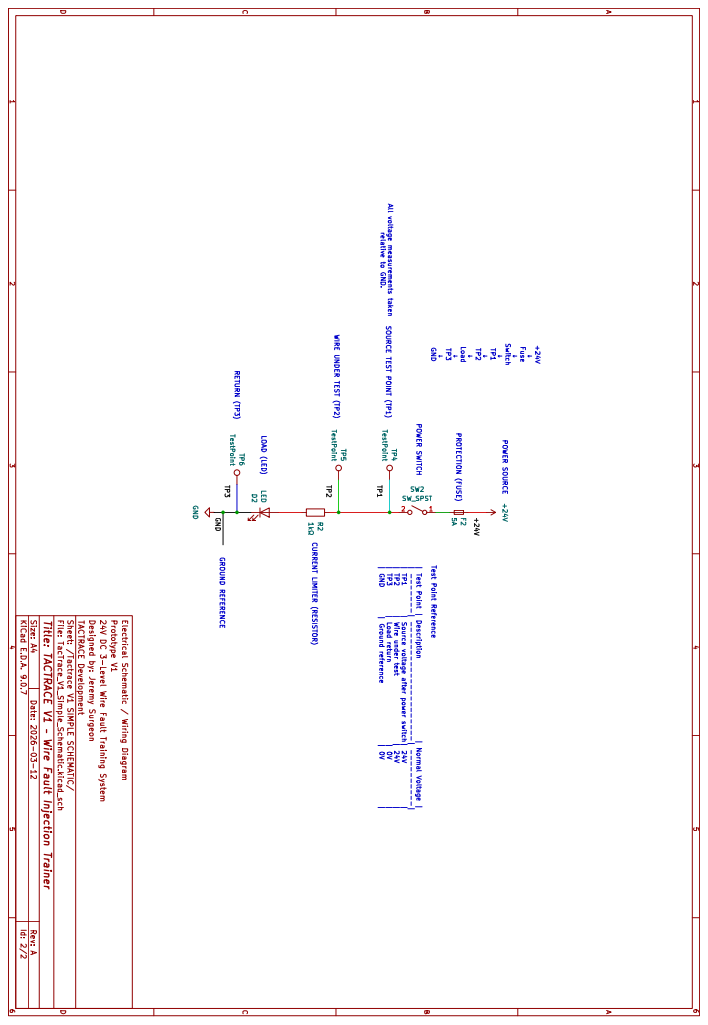
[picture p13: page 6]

# PART II — INSTRUCTOR REFERENCE

## Trainer Description

TACTRACE V1 is a fault injection trainer designed to simulate common wiring failures encountered in aircraft electrical systems.

The trainer simulates:

- Normal circuit operation
- Open wire faults
- Short-to-ground faults
- Short-to-power faults

These faults are selected using a 4-position rotary switch.

# Electrical Overview

Circuit path:

24V Supply

Fuse

Power Switch

TP1

Fault Selector (Rotary)

TP2

Resistor

LED

TP3

Ground

# Fault Selector Positions

# Expected Voltage Measurements

# Expected Resistance Measurements

Power OFF for all resistance/continuity checks.

Positio n | Fault Condition
1 | Normal
2 | Open Circuit
3 | Short to Ground
4 | Short to Power
Fault Mode | TP1 | TP2 | TP3 | LED
Normal | 24V | 24V | 0V | ON
Open Circuit | 24V | 0V | 0V | OFF
Short to Ground | 24V | 0V | 0V | OFF
Short to Power | 0V (switch off) | 24V | 0V | ON
Fault | TP2→GND | TP1→TP2 | TP2→TP3
Normal | Open / high Ω | Continuity | LED + resistor path
Open Circuit | Open / high Ω | Open / high Ω | LED + resistor path
Short to Ground | Continuity / very low Ω | Open / high Ω | Continuity / very low Ω
Short to Power | Open / high Ω | Open / high Ω | LED + resistor path

## Notes for the instructor

TP2→GND

- Normal: no direct short to ground, so this should read open or high resistance.
- Open: still open/high resistance.
- Short to Ground: this should read near 0 Ω or continuity.
- Short to Power: with power removed, this should usually read open/high resistance.

TP1→TP2

- Normal: continuity, because the source is connected through the normal path.
- Open: open, because the wire is intentionally disconnected.
- Short to Ground: open to TP1, because TP2 is being switched to ground instead of source.
- Short to Power: open to TP1, because TP2 is being switched to the alternate power path, not the normal switched path.

TP2→TP3

This one includes the load path, so you are measuring through the resistor and LED.

- On many meters, this will not give a simple continuity beep.
- It may show:
- a moderate or high resistance,
- an unstable reading,
- or OL depending on meter polarity and how the meter handles the LED.

So for trainee documentation, I would phrase this as:

# Instructor Setup Procedure

1. Ensure trainer is powered with 24V DC.
2. Turn POWER switch OFF.
3. Set rotary selector to desired fault condition.
4. Turn POWER switch ON.
5. Instruct trainee to begin troubleshooting.

# Instructor Evaluation

Fault | TP2→TP3 Expected
Normal | Load path present through resistor/LED
Open Circuit | Load path present through resistor/LED
Short to Ground | Near 0 Ω if TP2 is hard-grounded and TP3 is also at ground return
Short to Power | Load path present through resistor/LED
Student | Fault Set | Diagnosis | Pass/Fail

# System Verification

Before training begins, verify the trainer functions correctly.

Checklist:

☐ Power supply = 24V

☐ Fuse installed

☐ LED functional

☐ All four rotary positions verified

☐Test points produce correct readings

Notes
__________________________________________________

__________________________________________________

__________________________________________________

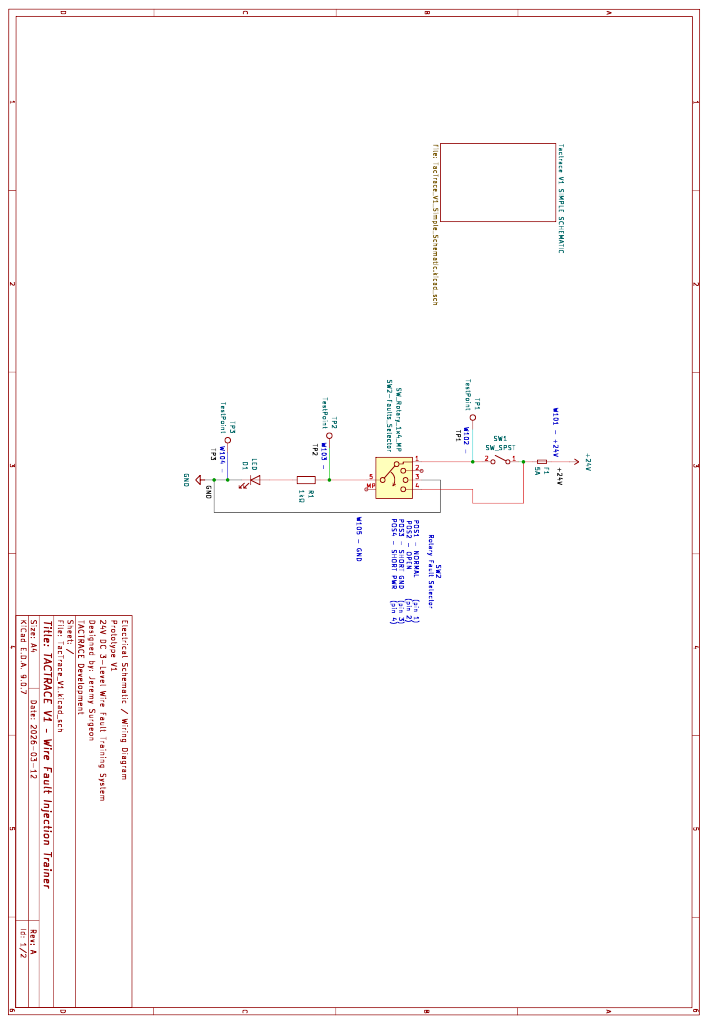
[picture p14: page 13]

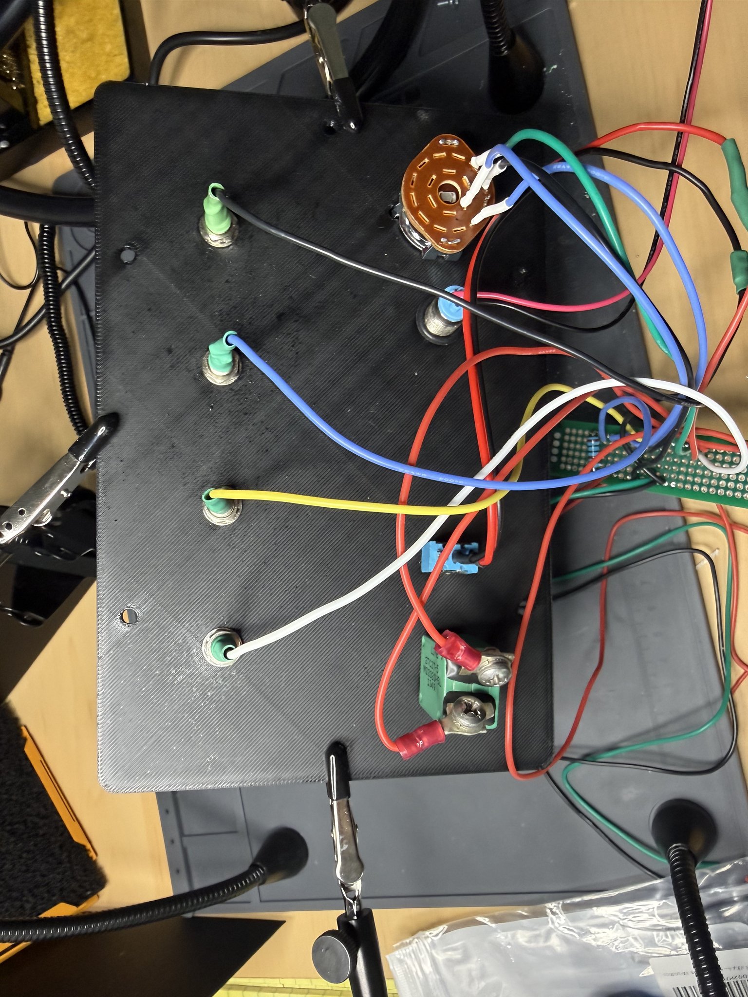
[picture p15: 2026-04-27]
images/v1_3_panel_wiring_underside.jpeg

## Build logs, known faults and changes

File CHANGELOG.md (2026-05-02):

# Changelog

All notable changes to the TACTRACE Trainer are documented in this file.

The format is based on [Keep a Changelog](https://keepachangelog.com/en/1.1.0/).
TACTRACE follows a versioned hardware revision scheme: V1.0 → V1.4 → V2.x.

---

## [V1.4] — 2026-04-14 — Rotary Selector Contact Protection Revision

### Added
- 100 nF ceramic capacitor connected from TP3 node to ground — for switching transient suppression during selector transitions.
- 100 Ω resistor on the **Position 4 (Short to Power)** path — for current limiting through the rotary contact during the Pos 4 transition.
- V1.4 simplified schematic (KiCad export).
- V1.4 lid-engraving art (panel quick-reference card with test point flow and system flow diagram).

### Changed
- Schematic annotation updated to reflect the V1.4 contact-protection components.
- Rotary selector standardized as **1P4T rotary selector switch** in all project documentation.

### Notes
- V1.4 contact-protection components reduce, but do not eliminate, switching transients on the rotary contacts. Quantitative validation under measured load is pending — flagged in the README as **"Needs peer review."**
- TACTRACE remains a bench-top trainer only; **no aircraft-airworthiness certification is claimed or implied**.

---

## [V1.4 Week 2 — Revision Pass] — 2026-05-01 — PII Masking, Quickstart Procedure, BOM Correction

### Added
- Two additional avionics-maintainer responses to the initial peer-feedback round, raising the sample to **n = 5** (two 3-Level Apprentices, two 5-Level Journeymen, one 7-Level Craftsman).

### Changed
- **`docs/TACTRACE_User_Feedback_Questionnaire.csv`** — surveyor identifying information masked. Names removed (responses listed as R1-R5), rank column removed, timestamps truncated to date only, AFSC / Career Field normalized to "Avionics" for all reviewers.
- **`docs/Peer_Feedback_Summary.md`** — updated to *n* = 5; respondent mix corrected to all-Avionics; reviewer headline ratings refreshed.
- **`docs/Quickstart.md`** — diagnostic procedure rewritten to make TP4 (GND) the explicit voltmeter reference, drop the implicit "voltage flows linearly down the chain" framing, and emphasize **comparison-based** troubleshooting. Added the V1.4 teaching note that **TP3 may remain energized in Pos 4 with the main switch off**.
- **`hardware/BOM.csv`** — perfboard specification confirmed at **2 cm x 8 cm** (was "2cm x 8cm assumed"); the matching Notes & Validation entry for perfboard dimensions is removed since it's no longer pending.
- **`hardware/BOM.pdf`** — regenerated from the corrected CSV.
- **`README.md`** — Validation & Initial Peer Feedback section refreshed to *n* = 5 with corrected respondent mix; deliverables table updated.

---

## [V1.4 Week 2] — 2026-04-29 — Hardware & Documentation Publication

### Added
- **Detailed V1.4 schematic** ([`hardware/schematics/v1_4_schematic_detailed.pdf`](hardware/schematics/v1_4_schematic_detailed.pdf)) — drawn at the component level with the 100 nF cap, 100 Ω resistor, 1P4T rotary positions (POS1 NORMAL / POS2 OPEN / POS3 SHORT GND / POS4 SHORT PWR), and TP1-TP4 banana-jack test points individually labeled.
- **Simplified V1.4 schematic** ([`hardware/schematics/v1_4_schematic_simplified.pdf`](hardware/schematics/v1_4_schematic_simplified.pdf)) — block-level orientation view.
- **V1.4 KiCad source** ([`hardware/kicad/`](hardware/kicad/)) — `.kicad_pro` plus the V1.4 simple and full schematic sheets.
- **Bill of materials**, machine- and human-readable: [`hardware/BOM.csv`](hardware/BOM.csv) and [`hardware/BOM.pdf`](hardware/BOM.pdf). Includes V1.4 line items (100 nF cap, 100 Ω resistor, lid engraving), V2 candidate parts on a separate sheet, and a Notes & Validation Items table.
- **V1.4 Quickstart** ([`docs/Quickstart.md`](docs/Quickstart.md)) — one-page reference for a maintainer who has never seen the device, including a teaching note on why TP3 still energizes in Pos 4 with the main switch off.
- **V1 Training Guide PDF** carried over as the interim training reference ([`docs/TACTRACE_V1_Training_Guide.pdf`](docs/TACTRACE_V1_Training_Guide.pdf)). The V1.4-revised guide that maps the V1 three-test-point set to the V1.4 four-test-point set is in progress.
- **User-feedback questionnaire** ([`docs/TACTRACE_User_Feedback_Questionnaire.csv`](docs/TACTRACE_User_Feedback_Questionnaire.csv)) — survey instrument for collecting trainee feedback.
- **Initial peer-feedback summary** ([`docs/Peer_Feedback_Summary.md`](docs/Peer_Feedback_Summary.md)) — five responses from avionics maintainers (two 3-Level Apprentice, two 5-Level Journeyman, one 7-Level Craftsman); preliminary, not a validation study. Surveyor identifying information masked in the underlying questionnaire CSV.
- README **Hardware & Documentation Deliverables** table, **Validation & Initial Peer Feedback** section, and **Enclosure Status** section.

### Changed
- README now embeds the **detailed** V1.4 schematic inline, replacing the simplified topology image as the canonical schematic figure.
- Hardware folder structure populated to match the layout described in [`hardware/README.md`](hardware/README.md): `kicad/`, `schematics/`, `BOM.csv`, `BOM.pdf`.
- The `archive/SCHEMATIC_V1_4_REGENERATION.md` regeneration TODO is now superseded for the inline image (resolved by `images/v1_4_schematic_detailed.png`); reference designators on V1.4 components remain pending — see the file itself.

### Deferred
- **Enclosure CAD** is intentionally deferred. The project is transitioning from FreeCAD to SolidWorks; the SolidWorks license is pending. The `hardware/enclosure/` folder is reserved and will be populated in a later revision.
- A full V1.4-revised training guide remains in progress. The V1 PDF is shipped as interim, and the V1.4 quickstart bridges the gap.

### Notes
- Initial peer feedback (n=3) indicates the trainer was usable and the test-point layout was clear to the reviewers. It does **not** establish training effectiveness across a representative cohort.
- "Resister" → "Resistor" typo corrected in the schematic source. Post-release housekeeping (reference designators, peer-review confirmation of the 100 Ω routing, component-rating confirmation) is tracked in [`archive/SCHEMATIC_V1_4_REGENERATION.md`](archive/SCHEMATIC_V1_4_REGENERATION.md).

---

## [V1.3] — 2026-03 — Test Point Architecture Refinement

### Changed
- Relocated TP1 to read protected input power (post-breaker, pre-switch).
- Separated circuit protection, control, and fault-injection stages into distinct measurable nodes (TP1 / TP2 / TP3 / TP4).

### Improved
- Diagnostic clarity for power distribution faults — trainees can now isolate breaker, switch, and selector failures independently.

---

## [V1.2] — Aircraft-Realism Pass

### Changed
- Replaced automotive fuse with aircraft-style 5 A pull-type circuit breaker.
- Transitioned from male banana plugs to panel-mounted female banana jacks.

### Improved
- Safety, standard-test-lead compatibility, and instructional realism.

---

## [V1.1] — Enclosure Integration

### Added
- Pelican 1120 enclosure with structured control panel layout.

### Improved
- Durability and portability for transport between training sites.

---

## [V1.0] — 2026-02 — Functional Validation

### Added
- Initial circuit concept and four-position rotary fault selector (Normal / Open / Short-to-Ground / Short-to-Power).
- 24 V DC supply, fuse, power switch, LED + 1 kΩ resistor load, banana-jack test points.
- Initial bench validation of all four fault conditions.

---

## Conventions

- Hardware revisions are tagged in this repository as `v1.0`, `v1.1`, `v1.2`, `v1.3`, `v1.4`, and so on.
- Each entry uses the **Added / Changed / Removed / Improved / Notes** sub-headings from Keep a Changelog where they apply.
- Claims that have not yet been validated by measured testing or independent peer review are marked **"Needs peer review"** in the README.

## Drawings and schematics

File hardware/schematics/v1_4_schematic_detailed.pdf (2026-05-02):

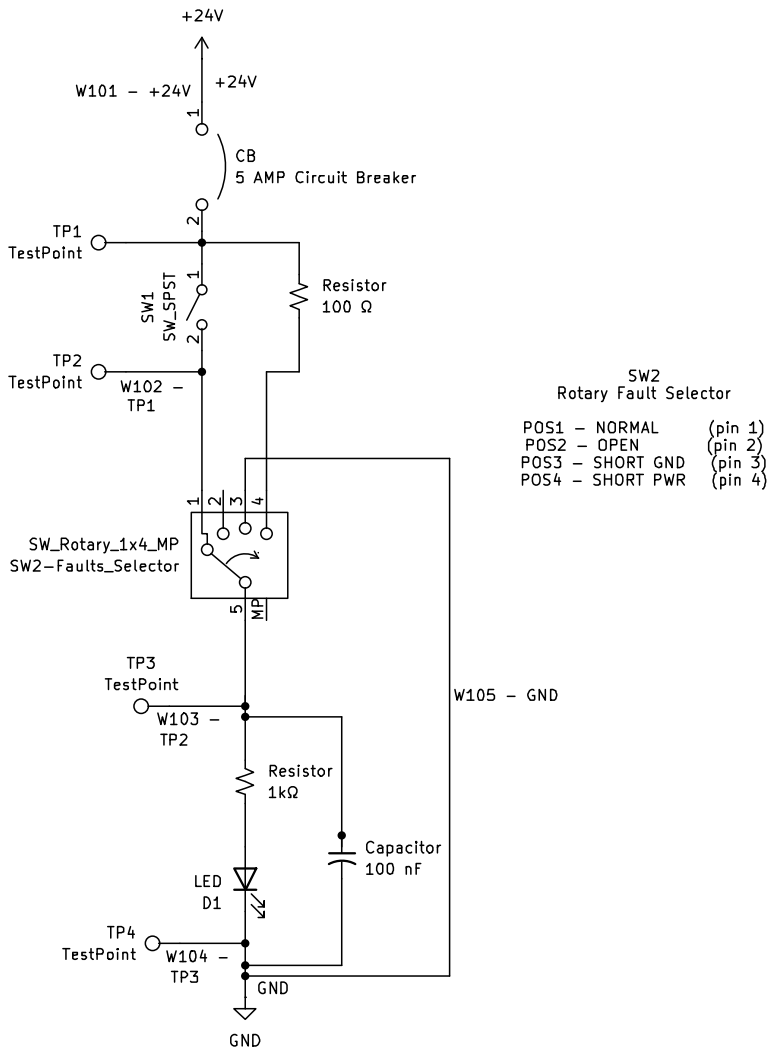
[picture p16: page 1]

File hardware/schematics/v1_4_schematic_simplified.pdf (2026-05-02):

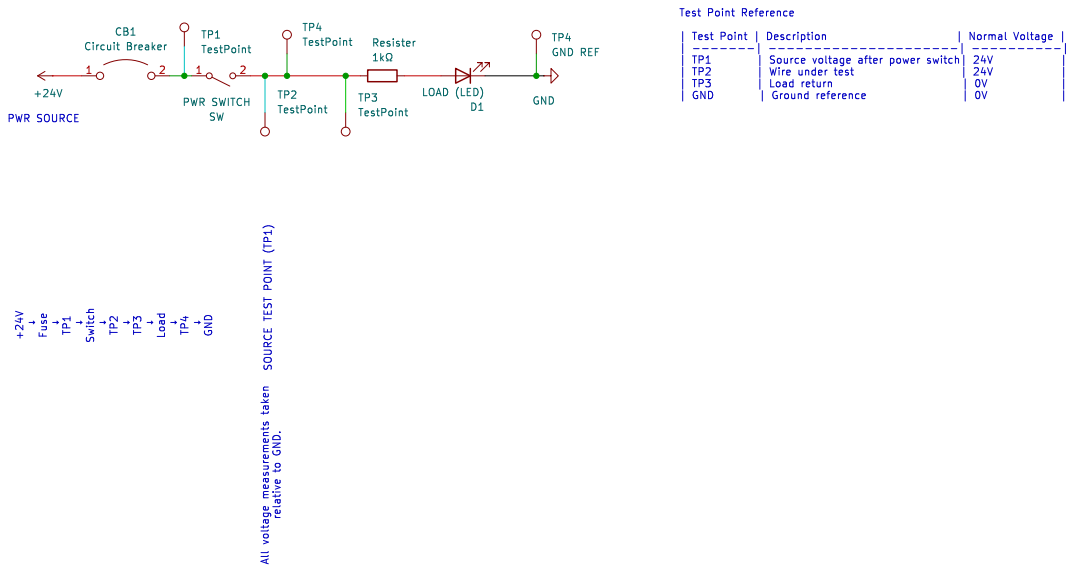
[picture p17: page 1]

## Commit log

2026-04-11 Revise README for TACTRACE Trainer details
    Updated README to enhance clarity and detail about the TACTRACE Trainer system, including sections on overview, purpose, current version, training use case, and lessons learned.
2026-04-29 Correct cannon connector description in README
2026-05-02 Update V1.4 images, archive legacy assets, refresh README
    [BOM.csv, TACTRACE_User_Feedback_Questionnaire.csv, TacTrace_V1_4_Full.kicad_sch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]
